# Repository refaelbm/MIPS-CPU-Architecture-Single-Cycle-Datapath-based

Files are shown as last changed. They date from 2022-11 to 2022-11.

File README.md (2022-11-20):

# MIPS-CPU-Architecture-Single-Cycle-Datapath-based

## Introduction:

The aim of this laboratory is to design a simple MIPS compatible CPU using FPGA. The CPU 
will use a Single Cycle MIPS architecture and must be capable of performing 
Instructions from the MIPS instruction set.

**Program languages:** VHDL, Assembly

**Programming Tools:** ModleSim, Quartus, IAR

## Design Scope:

 The architecture includes a MIPS ISA compatible CPU with data and program 
 memory Caches for hosting data and code.
 The GPIO (General Purpose I/O) is a simple decoder with buffer registers 
 Mapped to data address (Higher than data memory) to enable the CPU to output data to LEDs and 7-Segment and to read the Switches state.
 The CPU will be based on the standard 32bit MIPS ISA and the instructions will be 
 32 bit wide. 

 The following table shows the MIPS instruction format:

 

 #### The architecture has 6 design units implemented:
  1. Top level (MIPS)
     - The top level envelop toghter the other 5 design that we will talk about
  2. Control design
     - Doing the needed decoding
     - Manage the other units
     - Responsible for all the control lines, and putting the values in them according to the relevant command.      
  3. DeMemory
     - Unit that responsible for the write and reading in the memory    
  4. Execute
     - This is the unit that performs the arithmetic/logical operations that some commands require     
  5. IDeCode
     - This is the unit that decodes the command, and decides which registers are used.   
  6. IFetch
     - This is the unit that calculates the address of the next command to be executed, and calls the next command to be executed from memory.

## Verification Scope: 
 - Implemented with VHDL generator, function checker and coverage using ModelSim  
 - Loading the design into the FPGA using Quartus
  - Running simulations from the first implementation.
 - Running Assembly code that we implement in IAR

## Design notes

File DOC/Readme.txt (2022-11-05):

Task 3- MIPS Architecture
קובץ ReadMe

בקובץ זה, נפרט את מימוש התכנית עבור המודולים הבאים:

Control.vhd:
זוהי יחידת הבקרה, שבעצם מבצעת את פעולות הפיענוח, ניהול, ואחסון התוצאות המתקבלות.
כמו כן, אחראית על כל קווי הבקרה, והשמת הערכים בהם בהתאם לפקודה הרלוונטית.
מבחינת Entity-
יש לה 3 כניסות - reset ,clock ,opcode,
ו- 10 יציאות.

Dmemory.vhd:
זוהי היחידה שקשורה לזיכרון.
בעזרתה נוכל לקרוא/לכתוב נתון בזיכרון, במקרה של פקודת קריאה/כתיבה בזיכרון.
מבחינת Entity-
יש לה 6 כניסות,
ויציאה אחת - read_data.

Execute.vhd:
זוהי היחידה אשר מבצעת את הפעולות האריתמטיות/לוגיות שפקודה כלשהי דורשת.
מבחינת Entity-
יש לה 10 כניסות,
ו-4 יציאות - הראשונה היא התוצאה של פעולת ה-ALU.
ושלושת האחרות קשורות להסתעפות, אחת זה דגל zero, והשנייה הכתובת של ה-PC ,והשלישית זה דגל JR.

IDecode.vhd:
זוהי היחידה שמפענחת את הפקודה, ומחליטה באיזה רגיסטרים משתמשים.
מבחינת Entity-
יש לה 7 כניסות,
ו-3 יציאות - שתיים מהן יהיו read_data, והשלישית sign_extension.

IFetch.vhd:
זוהי היחידה שמחשבת את כתובת הפקודה הבאה לביצוע, וקוראת לפקודה הבאה לביצוע מהזיכרון.
מבחינת Entity-
יש לה 7 כניסות, ו-3 יציאות.

MIPS.vhd:
זוהי היחידה שעוטפת את התכנית כולה, ומה שמפעיל לנו את התכנית.
ה-MIPS מכיל את כל היחידות שכרגע הגדרנו, ומחבר ביניהם לקבלת מעבד Single Cycle.

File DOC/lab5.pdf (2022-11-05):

# Task 3- mips architecture

## קובץ 3TASK

### מגישים:

מתן אלמליח 205989486

רפאל 307999151

### תוכן עניינים

הסבר המטלה –------------------------------- עמ' .2

קובץ MIPS- -----------------------------------עמ' .3-5

קובץ IFETCH---------------------------------- עמ' .5-6

קובץ IDECODE------------------------------- עמ' .7-8

קובץ execute-------------------------------- עמ' .8-9

קובץ dmemory----------------------------- עמ' .10-11

קובץ control------------------------------- עמ' .12-13

דוגמאות לtap signal, ודיאגרמת wave-- עמ' .14

### הסבר המטלה:

עלינו לכתוב ארכיטקטורת CPU הכוללת ISA MIPS בעלת זכרון DATA ו PROGRAM עבור המידע והקוד. הכתיבה תהיה בצורת STRUCTURAL והמערכת עצמה מתוכננת באמצעות CYCLE SINGLE.

זכרון המערכת מחולק ל זכרון מידע וזכרון תכנית.

כמו כן, גודל הפקודות יהיה 32 ביט . המערכת עצמה תתמוך בפורמט הפקודות מהסוגים:

R type

I_TYPE

J_TYPE

הפקודות שמימשנו הן:

.Add, sub, addi, mul, and , or , xor, andi, ori, xori , sll, srl, move, lw, lui, beq, bne, slt, slti, j, jr, jal

עבור המערכת, קיים קובץ בדיקה אחד אותו נממש:

קובץ ASSEMBLY אשר ממיין מערך המכיל 8 איברים ומציג אותם ב0hex בלבד.

### תיאור הקבצים

### 1( קובץ MIPS

למעשה הקובץ מדמה לנו את הTOP המקשר בין שאר הקבצים של המערכת.

לקובץ יש 3 קווי בקרת כניסה:

- RESET- מאפס את המערכת במידה ולוחצים על 0key.
- CLOCK- שעון בתדר של MHZ.24
- SW- הוקטור שמכיל את ערך קובץ הבדיקה.

מלבדם, ישנם עוד 11 קווים ועוד 2 חוצצים )באפר(.

קווי מוצא אלה אחראים על הקריאה והכתיבה לזכרון, ל-IO או מה-IO.

- PC- וקטור באורך 10 ביטים המייצג את הפקודה הבאה בזכרון.
- leds_Green,leds_Red – וקטורים באורך של 8 ביטים המייצגים את הלדים.
- 3HEX2,HEX1,HEX0,HEX- וקטורים באורך 7 ביטים המייצגים את המספרים המיוצגים על החומרה.
- out_Instruction- וקטורים באורך 32 ביט המייצגים את הפקודות אותן אנו מממשים.
. | בודד | ביט | בגודל | בקרה | קווי | -Branch_out,zero_out,memwrite_out,regwrite_out | -

-Logic usage

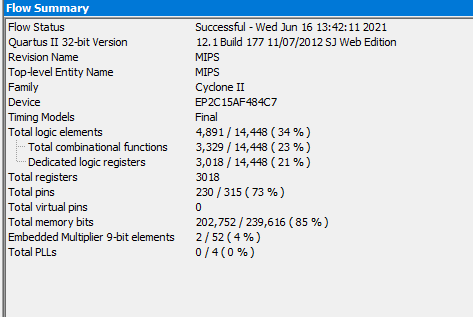
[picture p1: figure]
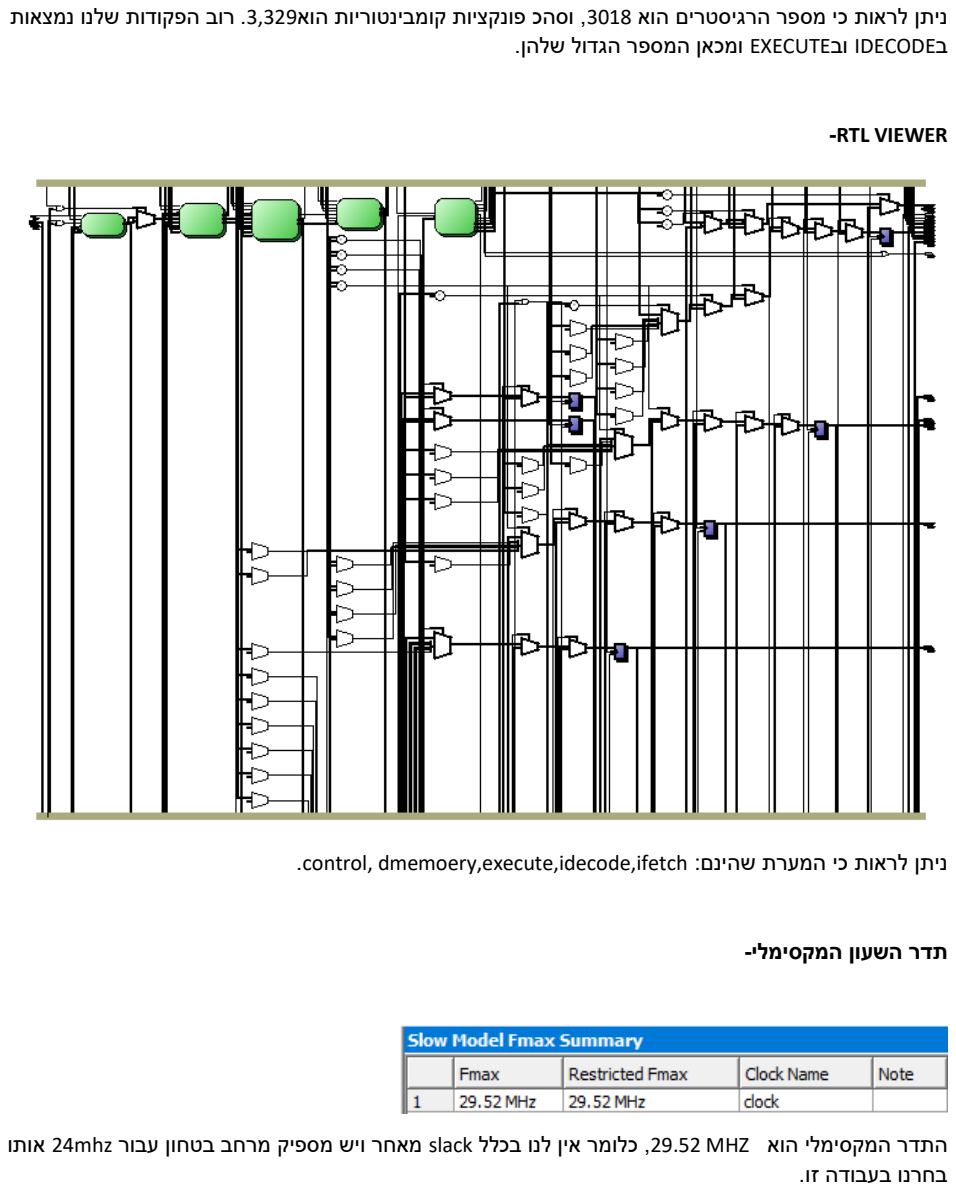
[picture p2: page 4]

ניתן לראות כי מספר הרגיסטרים הוא ,3018 וסהכ פונקציות קומבינטוריות הוא .3,329 רוב הפקודות שלנו נמצאות בIDECODE ובEXECUTE ומכאן המספר הגדול שלהן.

-RTL VIEWER

ניתן לראות כי המערת שהינם: ifetch,idecode,execute,dmemoery ,control.

תדר השעון המקסימלי -

התדר המקסימלי הוא MHZ ,29.52 כלומר אין לנו בכלל slack מאחר ויש מספיק מרחב בטחון עבור mhz24 אותו בחרנו בעבודה זו.

CRITCAL PATH

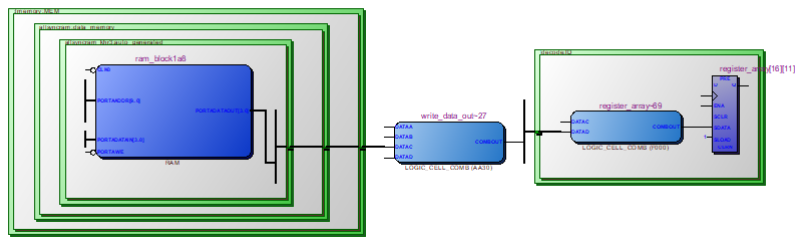
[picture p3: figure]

## 2( קובץ IFETCH

הרכיב מקבל כתובת אשר מייצגת את הפקודה בזכרון וניגש אליו עבור הפקודה. יתר על כן, ישנה החלטה מהי הפקודה הבאה שאלי יעבור ה PC.

יש מספר קווי בקרה שהקובץ מקבל עבור מצב הPC:

Reset, clock, zero, jump, branch_not, branch -

- result Add- הוקטור שמייצג את הכתובת בה שמורה הפקודה שאמורים לבצע. אורכו 8 ביטים.

מוצאי הרכיב -

- Instruction- וקטור בעל אורך של 32 ביטים ומכיל את הפקודה הנדרשת לביצוע.
- out 4plus pc ,out-Pc- וקטורים באורך 10 ביטים המכילים את הכתובת הבאה שהPC ניגש אליה.

-Logic usage

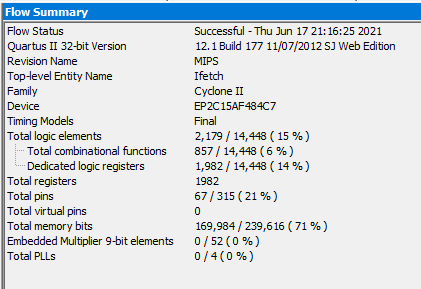
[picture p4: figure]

תיאור גרפי -

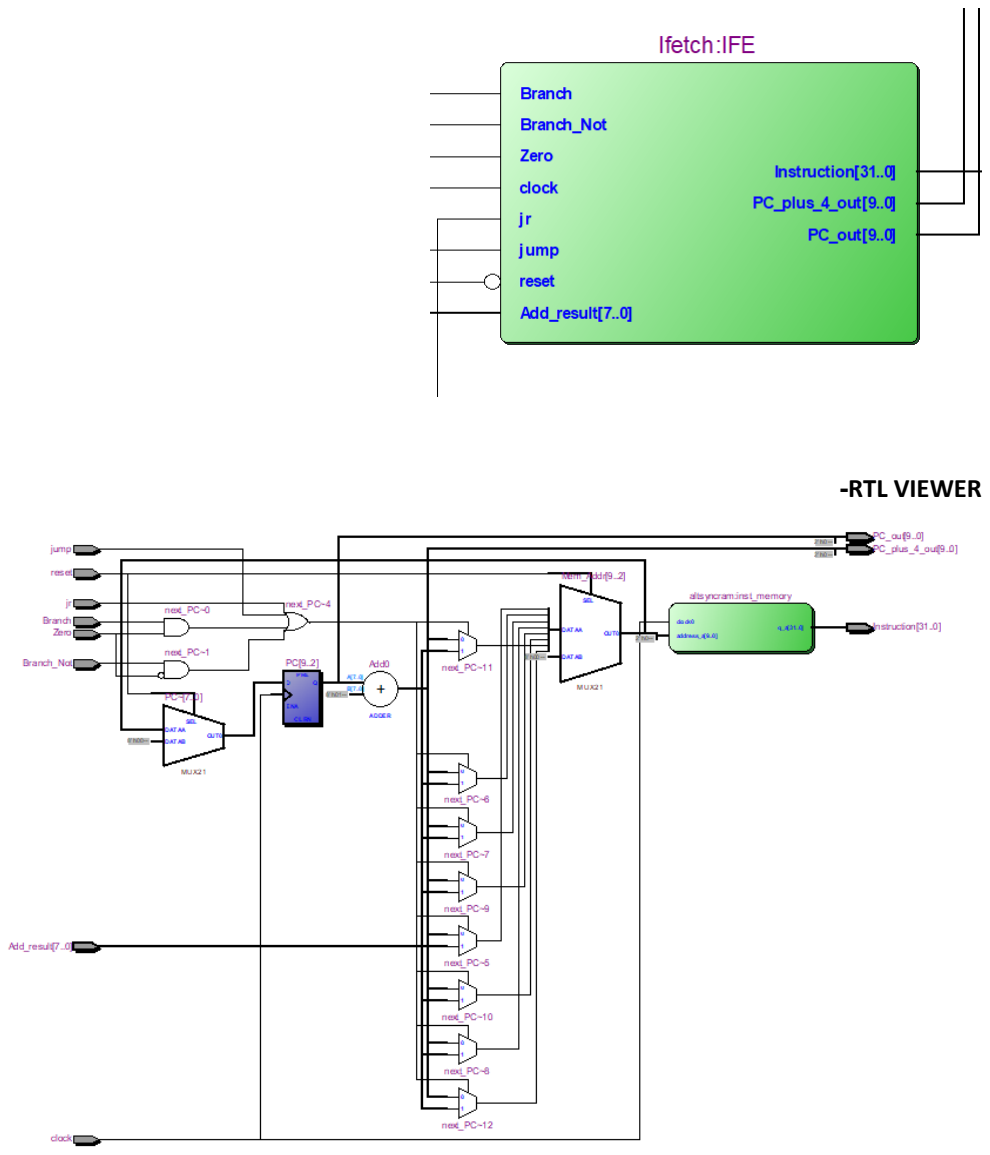
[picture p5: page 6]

-RTL VIEWER

## 3( קובץ idecode-

הרכיב מקבל -

- Instruction- וקטור בעל 32 ביטים המכיל את הפקודה שצריך לבצע כרגע.
- data Read- וקטורים באורך 32 ביטים המכילים מידע מהזכרון.
- result Alu- וקטור באורך של 32 ביט המייצג את התוצאה אליה אמורים לכתוב.
- memtoreg,regdst ,Regwrite-קווי בקרה אחראיים על כתיבה לזכרון ולרגיסטרים
- reset ,Clock – קווי בקרה עבור שעון ואתחול. קווי בקרה עבור שעון ואתחול.

קווי המוצא של הרכיב :

- 2 read data 1, read Data- באורך 32 ביט המכילים את המידע שהיה ברגיסטרים שמשתתפים בפקודה.
- extend Sign- וקטור באורך של 32 ביט שהמידע בו היה בפקודה.

:Logic usage

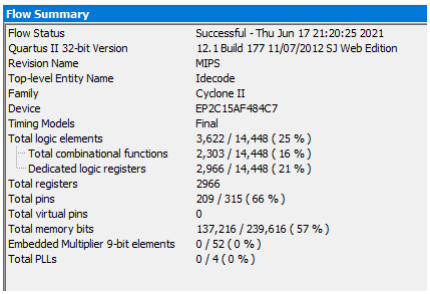
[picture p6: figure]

תצורה גרפית-

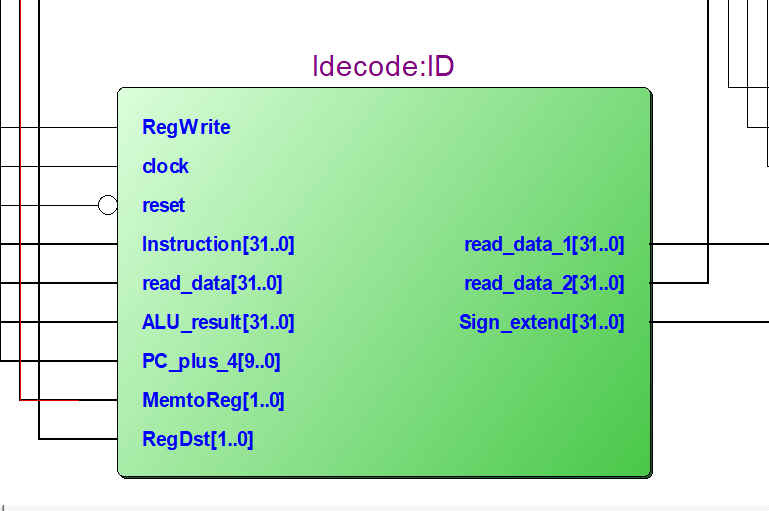
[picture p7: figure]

-Rtl viewer

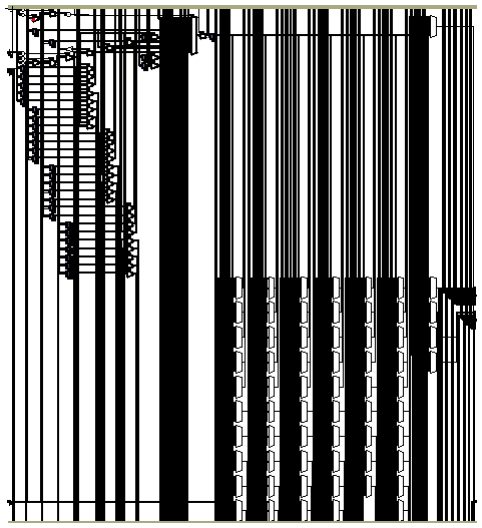
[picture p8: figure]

## 4( קובץ execute-

הרכיב מקבל :

.IDECODEה | ברכיב | הנוצרו | ביט | 32 | באורך | וקטורים | -Data read 1, data read 2, sign extend | -
- opcode Another, opcode function- וקטורים באורך 6 ביט המייצגים את הOPCODE של הפקודה שצריכים לבצע.
- ALUop- וקטור באורך 2 ביט העוזר בבחירה בין פקודות ברגע שיש ה תנגשות.
- ALUsrc- קו בקרה העוזר בבחירה ש בין פקודות ברגע שיש התנגשות.

- Jump- קו בקרה המייצג אם אמורים לבצע קפיצה בפקודות
- Clock,rest - קווי בקרה עבור שעון ואתחול.
- 4 plus Pc- וקטור באורך 10 ביט שמכיל את כתובת הפקודה הבאה.
- קווי המוצע של הרכיב:
- result Alu- וקטור באורך 32 ביט המכיל א ת התוצאה מה ALU
- result Add- וקטור באורך 8 ביט המכיל את הכתובת אליה עוברים.

-Logic usage

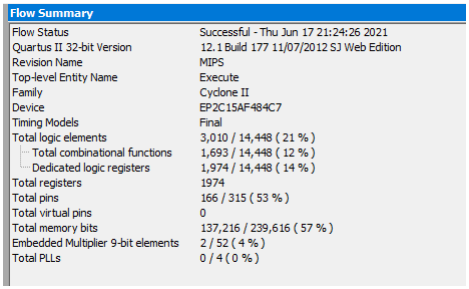
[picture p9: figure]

- תצוגה גרפית –

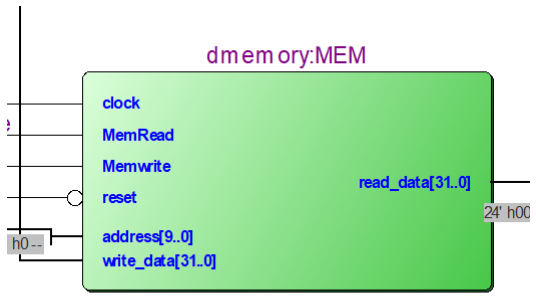
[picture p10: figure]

Rtl viewer

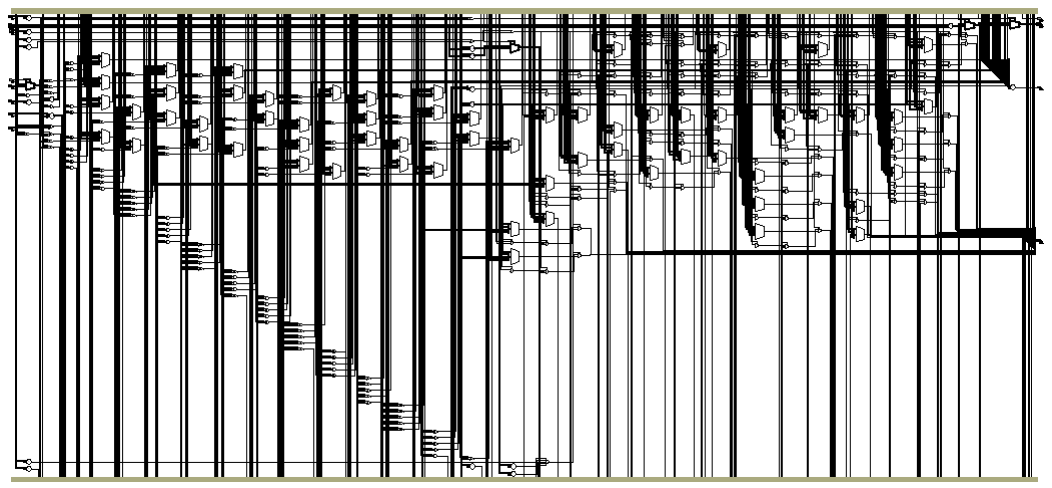
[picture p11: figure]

5( קובץ dememory-

קווי הכניסה של הרכיב הם:

- Adress- וקטור באורך 10 בי ט המכיל את הכתובת ממנה קוראים או שכותבים אליה.
- data Write- וקטור באורך 10 ביט נכתב לaltsyncram.
- Memwrite- קו בקרה נכתב עבור לaltsyncram
- Memread- לא בשימוש
- reset ,Clock – בקרה עבור שעון ואתחול.

מוצא הרכיב הוא:

data Read- וקטור באורך 32 ביט המכיל את המידע שנ קרא מהזכרון

-Logic usage

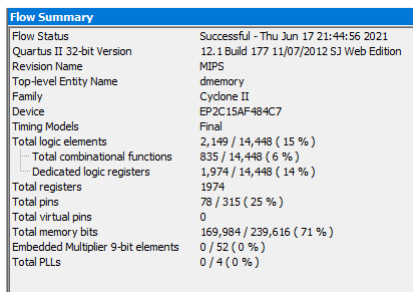
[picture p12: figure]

תצוגה גרפית -

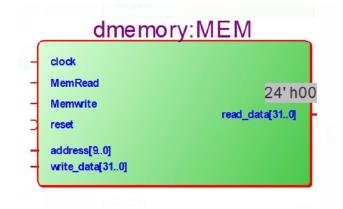
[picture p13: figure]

-Rtl viewer

6( קובץ CONTROL-

קווי הכניסה של הרכיב הם:

- Opcode- וקטור באורך 6 ביט המכיל את הOPCODE של הפקודה המבוצעת
- reset ,Clock- קווי בקרה עבור שעון ואתחול

קווי המוצא של הרכיב הם:

Regdst | -
Alusrc | -
Memtoreg | -
Memdread | -
Memwrite | -
Branch | -
Branch not | -

Jump | -
ALUop | -
Clock reset | -

Logic usage

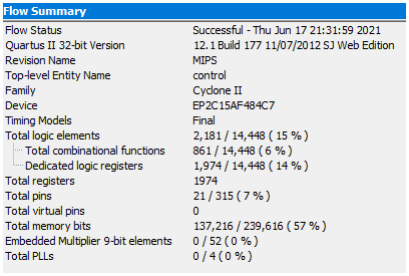
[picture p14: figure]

תצורה גרפית-

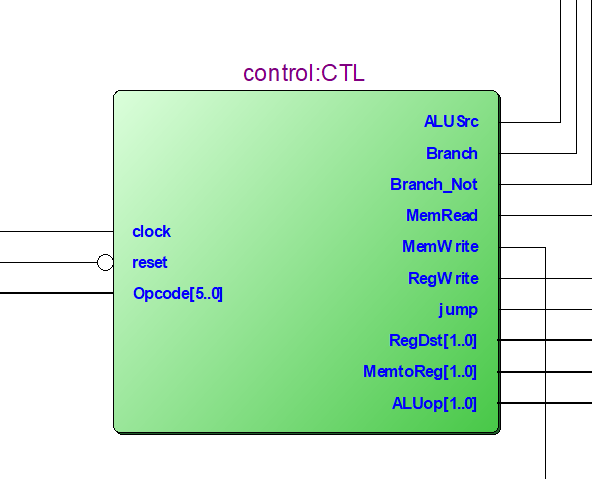
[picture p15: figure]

Rtl viewer

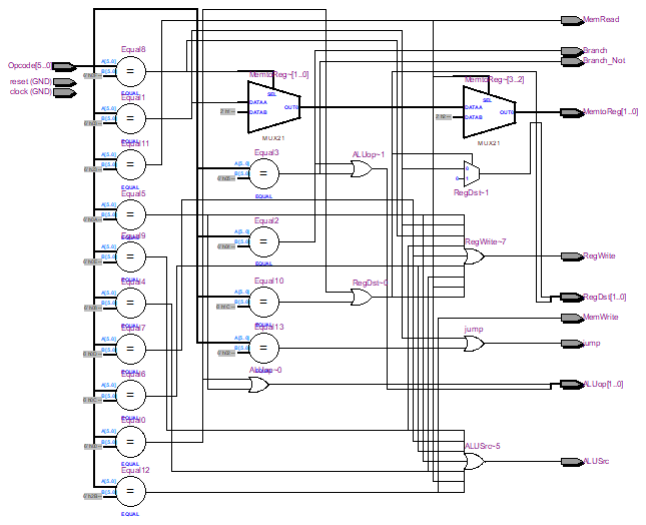
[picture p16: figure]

דוגמא לדיאגרמת WAVE:

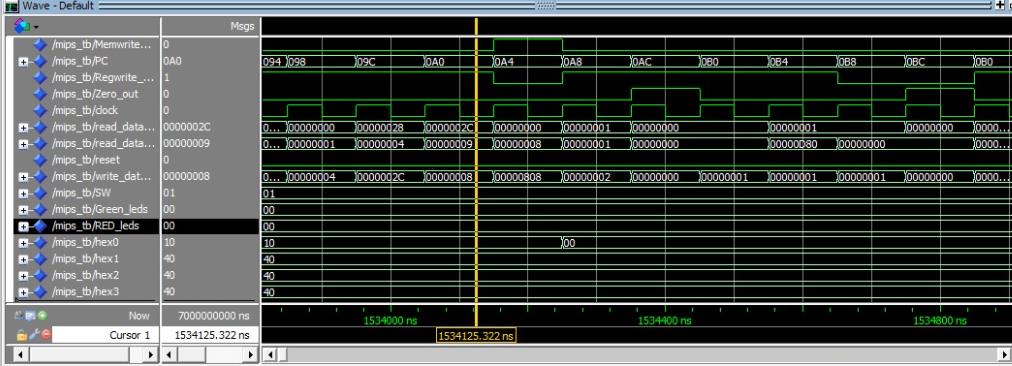
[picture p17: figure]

דוגמא לtap signal:

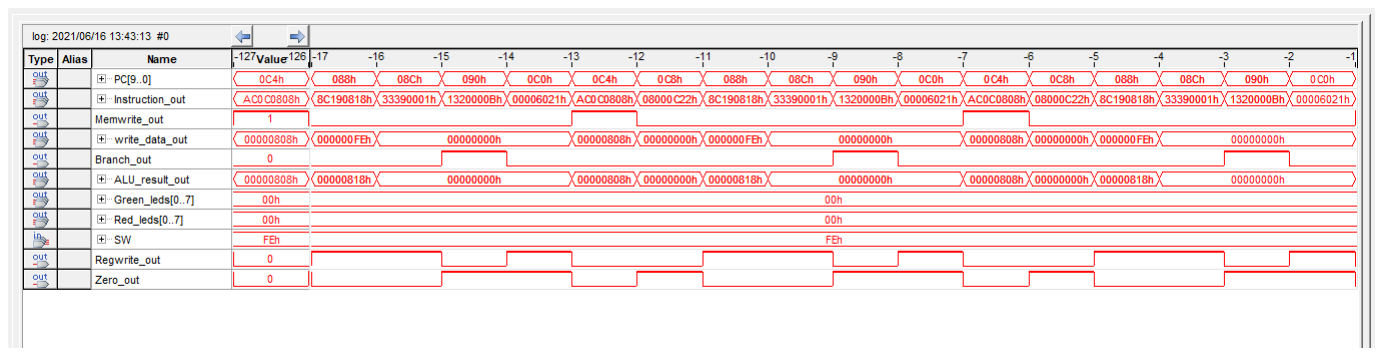
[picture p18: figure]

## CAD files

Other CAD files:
QUARTUS/stp2.stp
